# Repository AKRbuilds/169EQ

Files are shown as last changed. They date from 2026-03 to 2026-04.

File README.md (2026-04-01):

# Studer 169 EQ (API 500 Format)

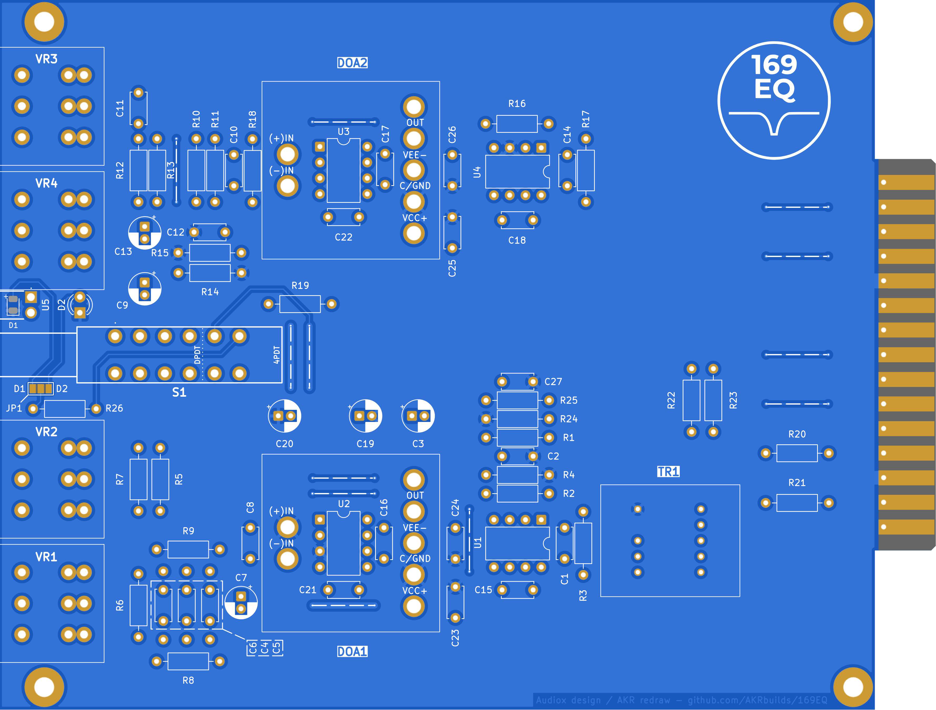
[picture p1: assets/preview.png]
PCB Preview


This project is a reproduction of the **Studer 169 EQ** for the **API 500 series** format. Based on the original design by *AUDIOX* on GroupDIY.

---

## ❤️ Support the Development
Redrawing this board took quite some time. If this project helps your studio or saves you time, **consider buying me a coffee!** Your support keeps me runing.



---

## One-Click Manufacturing
Get your PCBs made with the exact specifications by using the official PCBWAY shared project link:



> You can also  [Download the Latest Gerber Files (ZIP)](https://github.com/AKRbuilds/169EQ/releases/latest) to use with any manufacturer.

---

## Improvements in this Version
* **Redrawn Layout:** 2-layer board with top-side jumpers.
* **4PDT Switch Support:** New footprint for 4PDT switches + Bypass LED (fully compatible with original SPDT).
* **LED Options:** Choose between **SMD + Light Pipe (U5)** or standard **THT LED** via jumper **JP1**.
  
---

## 📄 Documentation
* 📄 Launch interactive BOM [**WITH** Neutrik transformer](https://htmlpreview.github.io/?https://github.com/AKRbuilds/169EQ/blob/main/assets/ibom_with_neutrik.html) / [**WITHOUT** 🔴 Neutrik transformer](https://htmlpreview.github.io/?https://github.com/AKRbuilds/169EQ/blob/main/assets/ibom_without_neutrik.html)
* 📄 PCB Assembly Overview (PDF) [**WITH** Neutrik transformer](assets/Layout_with_neutrik.pdf) / [**WITHOUT** 🔴 Neutrik transformer](assets/Layout_without_neutrik.pdf)
* 📄 [Bom (CSV)](assets/bom.csv) / [Bom (PDF)](assets/bom.pdf)
* 📄 [KiCad Schematics (PDF)](assets/Schematics.pdf)
* 📄 [Original Schematics (PDF)](assets/original_schematics.pdf)
* 📄 [Front Panel Guide (PDF)](assets/front_panel.pdf) | 📥 [Download FPD File](assets/front_panel.fpd)
* 📄 [Supporting Hardware (PDF)](assets/hardware.pdf)
* 🔗 Front panels available here: [Frontpanels.de](https://groupdiy.com/threads/studer-169-eq-in-api-500-format.36522/)
---

## 🔗 Credits & Community
* **Original Project:** Original design by **AUDIOX**.
* **Join the Discussion:** [Build Thread on GroupDIY](https://shop.frontpanels.de/FIlter/Equalizer)

## License
Licensed under **CERN-OHL-S v2**.

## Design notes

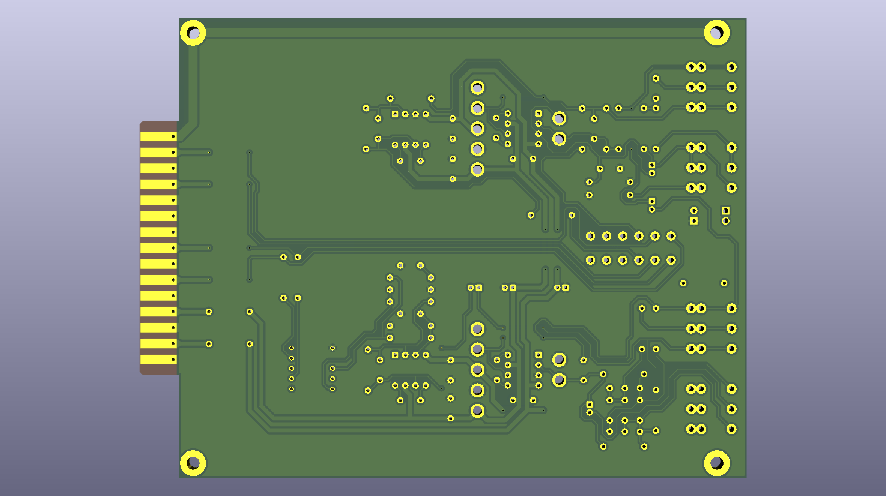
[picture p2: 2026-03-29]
assets/preview_back.png

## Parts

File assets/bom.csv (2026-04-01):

Designator | Footprint | Quantity | Value with Neutrik | Value without Neutrik | Man. Pr. Nr.
Capacitors
C1 | C_Disc_D5.0mm_W2.5mm_P5.00mm | 1 | Do not place | 47p
C10, C14, C2, C8 | C_Disc_D5.0mm_W2.5mm_P5.00mm | 4 | 47p | 47p
C11 | CAP FILM P5.00mm | 1 | 15n | 15n
C12, C4, C5 | CAP FILM P5.00mm | 3 | 10n | 10n
C13, C3, C7, C9 | CP_Radial_D5.0mm_P2.00mm | 4 | 100uf/10V | 100uf/10V
C15, C16, C17, C18 | C_Disc_D5.0mm_W2.5mm_P5.00mm | 4 | 22p | 22p
C19, C20 | CP_Radial_D5.0mm_P2.00mm | 2 | 10uf/25V | 10uf/25V
C21, C22, C23, C24, C25, C26 | C_Disc_D5.0mm_W2.5mm_P5.00mm | 6 | 100n | 100n
C27 | C_Disc_D5.0mm_W2.5mm_P5.00mm | 1 | 150p | Do not place
C6 | CAP FILM P5.00mm | 1 | 220n | 220n
Transformer
TR1 | NTL1 | 1 | NTL1 | Do not place and Bridge JP2 and JP3
ICs
DOA1 | DOA_2520 - Don't place U2 if used | 1 | DOA1 | DOA1
DOA2 | DOA_2520 - Don't place U3 if used | 1 | DOA2 | DOA2
U1, U4 | DIP-8_W7.62mm | 4 | NE5534 | NE5534
U2, U3 | Place if DOA not used | 4 | NE5534 | NE5534
Resistors
R1 | R_Axial_DIN0207_L6.3mm_D2.5mm_P10.16mm_Horizontal | 1 | Do not place | 20K
R2 | R_Axial_DIN0207_L6.3mm_D2.5mm_P10.16mm_Horizontal | 1 | WIRE | 20K
R3 | R_Axial_DIN0207_L6.3mm_D2.5mm_P10.16mm_Horizontal | 1 | 1K | 10K
R10, R11, R16, R17 | R_Axial_DIN0207_L6.3mm_D2.5mm_P10.16mm_Horizontal | 4 | 10K | 10K
R4 | R_Axial_DIN0207_L6.3mm_D2.5mm_P10.16mm_Horizontal | 1 | 5K6 | 10K
R12, R14 | R_Axial_DIN0207_L6.3mm_D2.5mm_P10.16mm_Horizontal | 2 | 1K8 | 1K8
R13, R15 | R_Axial_DIN0207_L6.3mm_D2.5mm_P10.16mm_Horizontal | 2 | 680K | 680K
R18, R19 | R_Axial_DIN0207_L6.3mm_D2.5mm_P10.16mm_Horizontal | 2 | 22R | 22R
R20, R21 | R_Axial_DIN0207_L6.3mm_D2.5mm_P10.16mm_Horizontal | 2 | 10R | 10R
R22, R23 | R_Axial_DIN0207_L6.3mm_D2.5mm_P10.16mm_Horizontal | 2 | 1K6 | 10R
R24 | R_Axial_DIN0207_L6.3mm_D2.5mm_P10.16mm_Horizontal | 1 | WIRE | Do not place
R25 | R_Axial_DIN0207_L6.3mm_D2.5mm_P10.16mm_Horizontal | 1 | 15K | Do not place
R26, R6, R7 | R_Axial_DIN0207_L6.3mm_D2.5mm_P10.16mm_Horizontal | 3 | 3K3 | 3K3
R5 | R_Axial_DIN0207_L6.3mm_D2.5mm_P10.16mm_Horizontal | 1 | 560R | 560R
R8, R9 | R_Axial_DIN0207_L6.3mm_D2.5mm_P10.16mm_Horizontal | 2 | 220K | 220K
Others
S1 | 4PDT F4UEE to use LED / DPDT F2UEE no LED | 1 | 4PDT/DPDT | 4PDT/DPDT | MPBS-42H01L-F14
D1 | 805 Choose between D1 and D2 and jump JP1 accordingly | 1 | LED | LED | 150080AS75000 works great even without light pipe
D2 | LED_D3.0mm | 1 | LED | LED
U5 | SLP3250100F - Led pipe | 1 | LED Pipe | LED Pipe | SLP3-250-100-F
VR1 | PC2G16BU | 1 | 2x22KLin | 2x22KLin | OM-01-023 | available at audiomaintenance.com
VR2, VR3 | PC2G16BU 16mm dual gang pots | 2 | 2x10KLin | 2x10KLin | OM-01-005
VR4 | PC2G16BU 16mm dual gang pots | 1 | 2x100KRLog | 2x100KRLog | OM-01-059
DOA Pin Receptacles | Mill-Max 0322 | 12 |  |  | 0322-0-15-01-34-27-10-0 For gold ones: 0322-0-15-15-34-27-10-0

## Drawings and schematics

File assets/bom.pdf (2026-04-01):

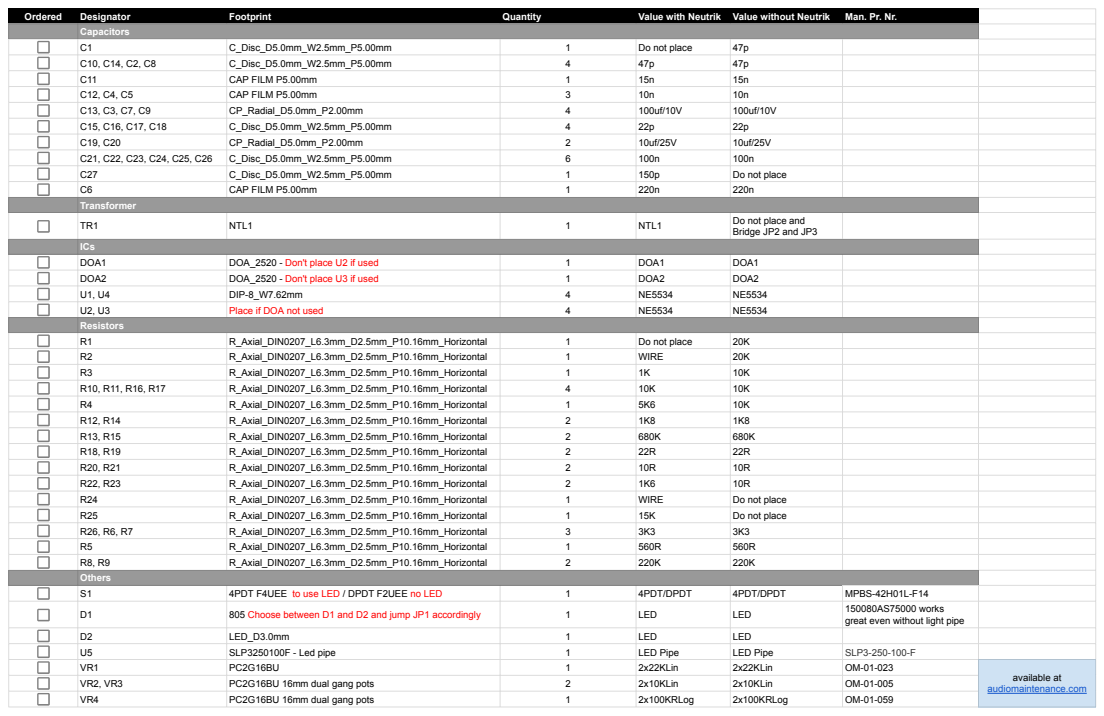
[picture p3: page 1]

Don't place U2 if used
Don't place U3 if used

Place if DOA not used

Others

150080AS75000 works
great even without light pipe

D1 805 Choose between D1 and D2 and jump JP1 accordingly 1 LED LED D2 LED_D3.0mm 1 LED LED VR1 PC2G16BU 1 2x22KLin 2x22KLin VR4 PC2G16BU 16mm dual gang pots 1 2x100KRLog 2x100KRLog

SLP3-250-100-F

OM-01-023 OM-01-059 | audiomaintenance.com

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
Mill-

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
s: 0322-0-15-15-
3

4

2

7

1

0

0

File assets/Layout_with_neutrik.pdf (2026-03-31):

R14 | C22 | R²² C⁴ C12 D² | C9 | R¹³ | C⁵ C¹¹ 1 | 2 | 3 | 4 | 5 | 6 1 | 2 | 3 | 4 | 5 | 6 ABCD | ABCD Date: 2026-03-13 KiCad | E.D.A. 9.0.7 Size: A4 | Rev: 1

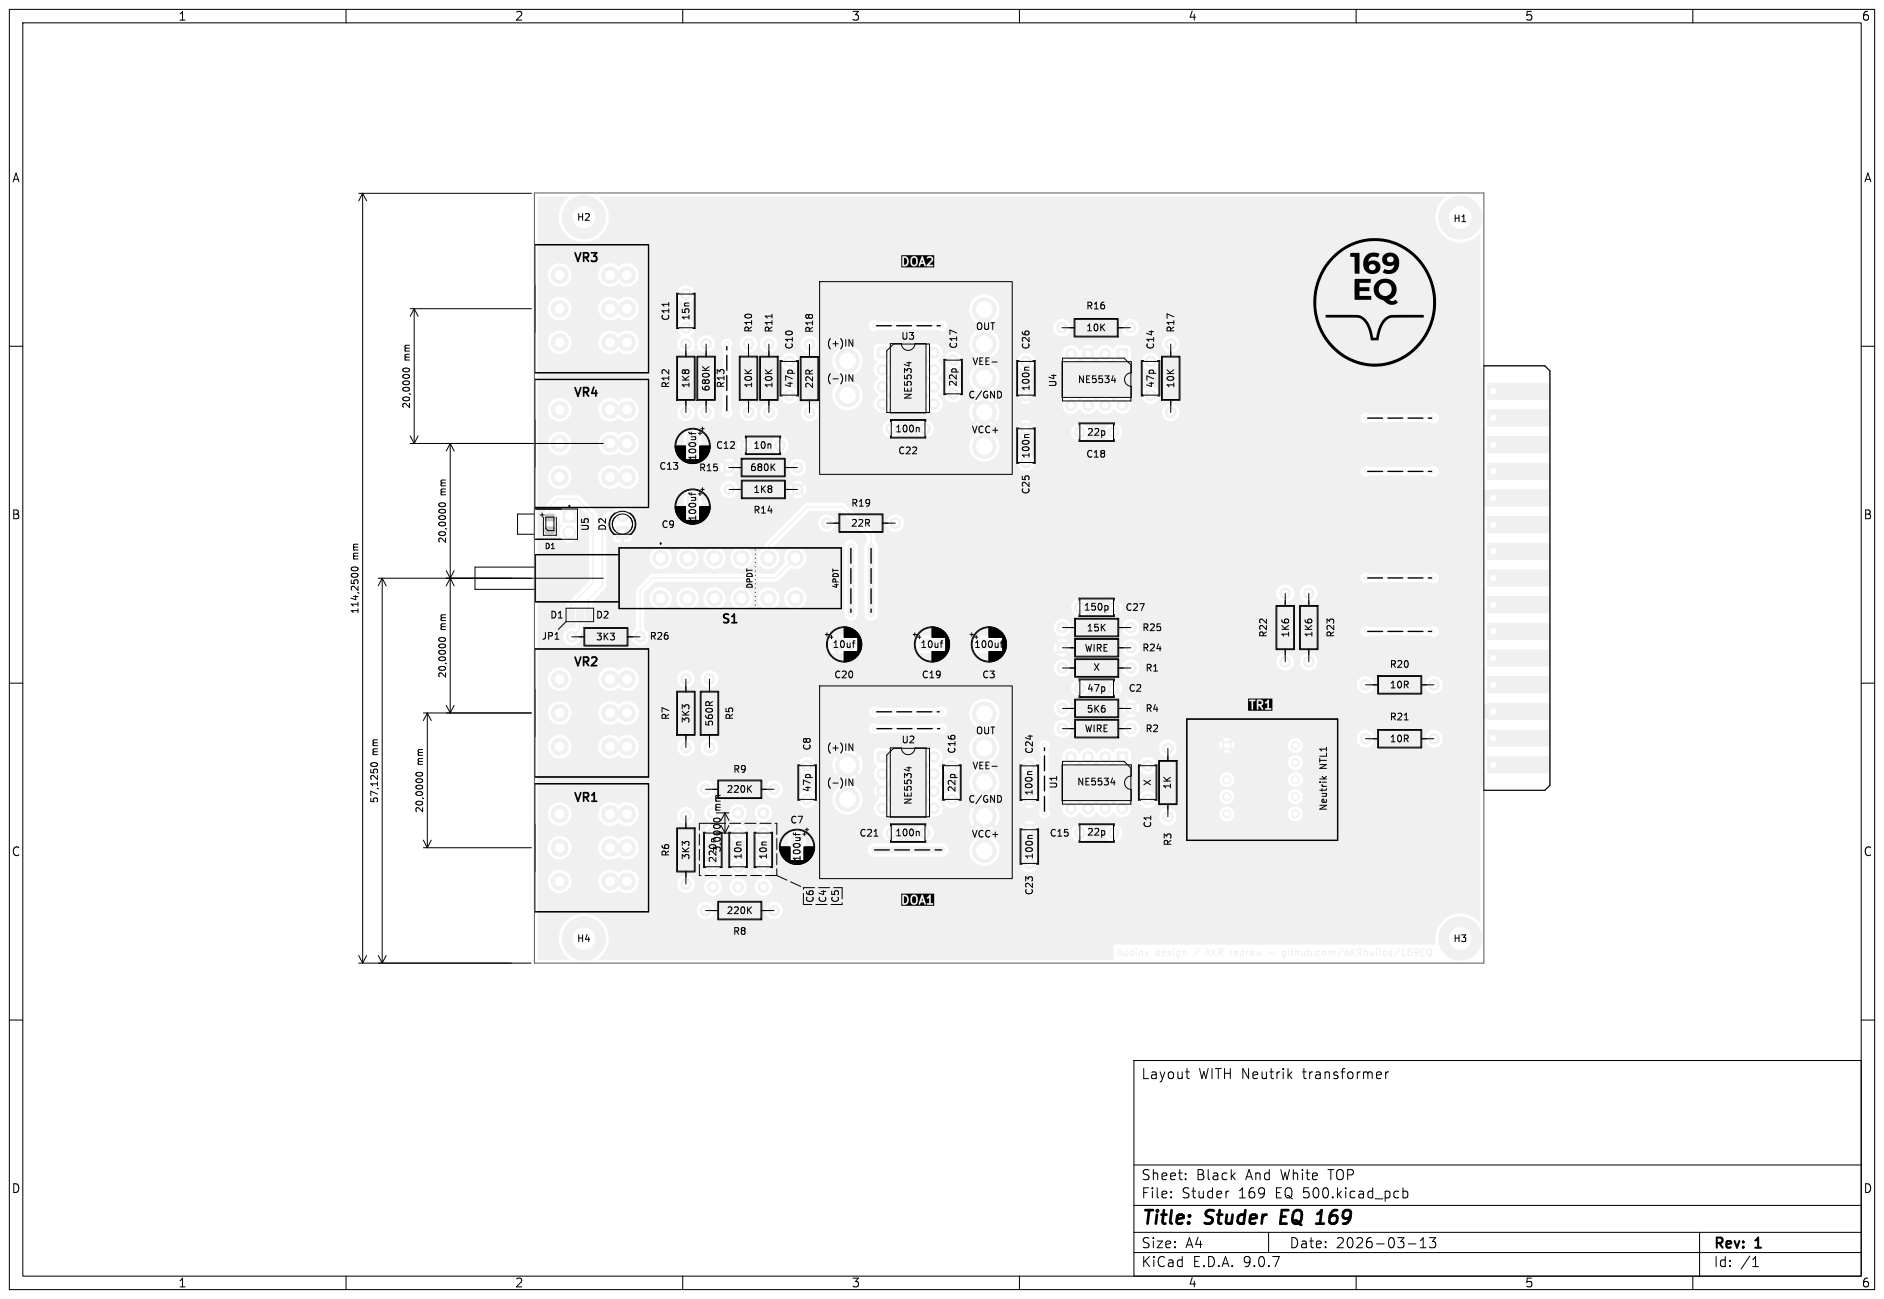
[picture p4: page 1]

Id: /1 Title: Studer EQ 169

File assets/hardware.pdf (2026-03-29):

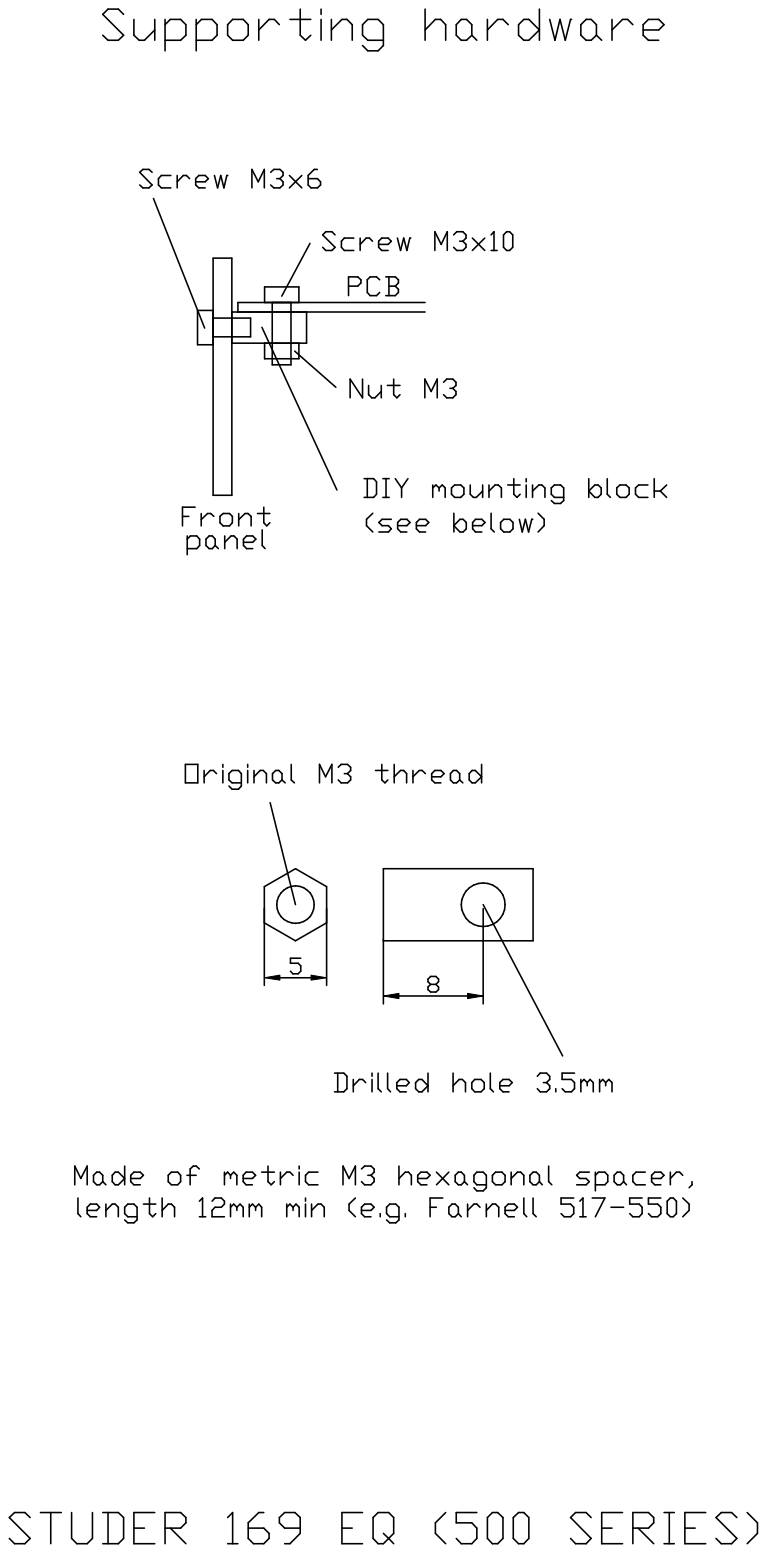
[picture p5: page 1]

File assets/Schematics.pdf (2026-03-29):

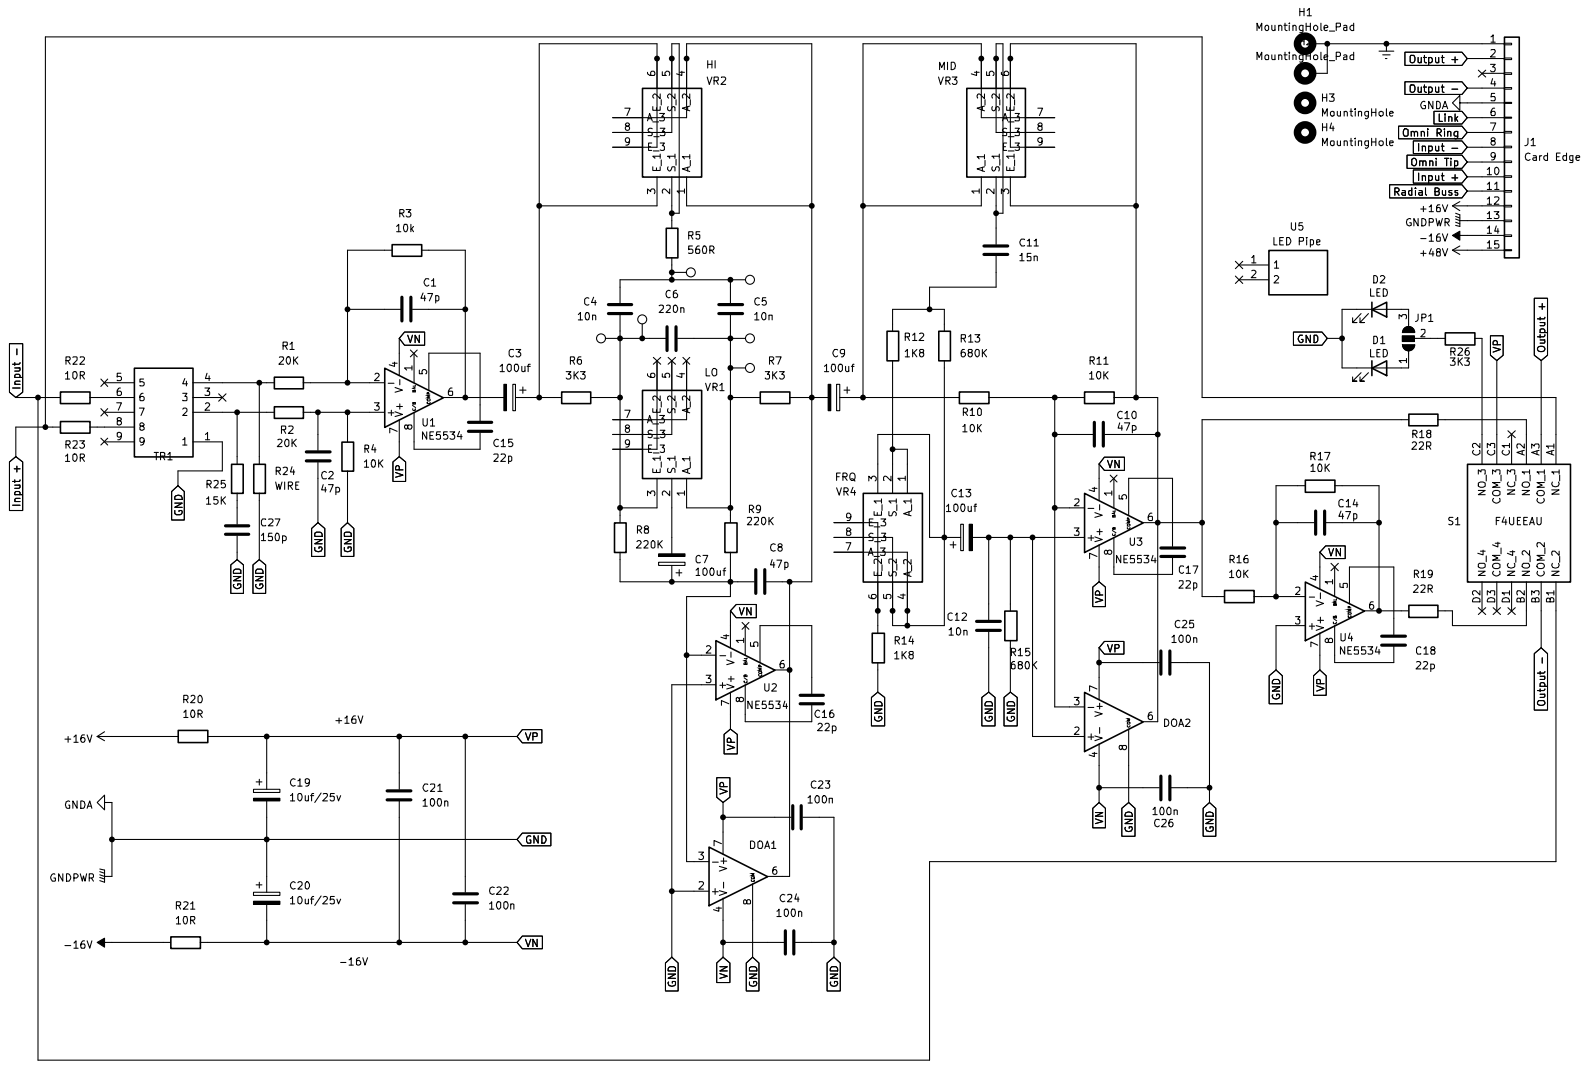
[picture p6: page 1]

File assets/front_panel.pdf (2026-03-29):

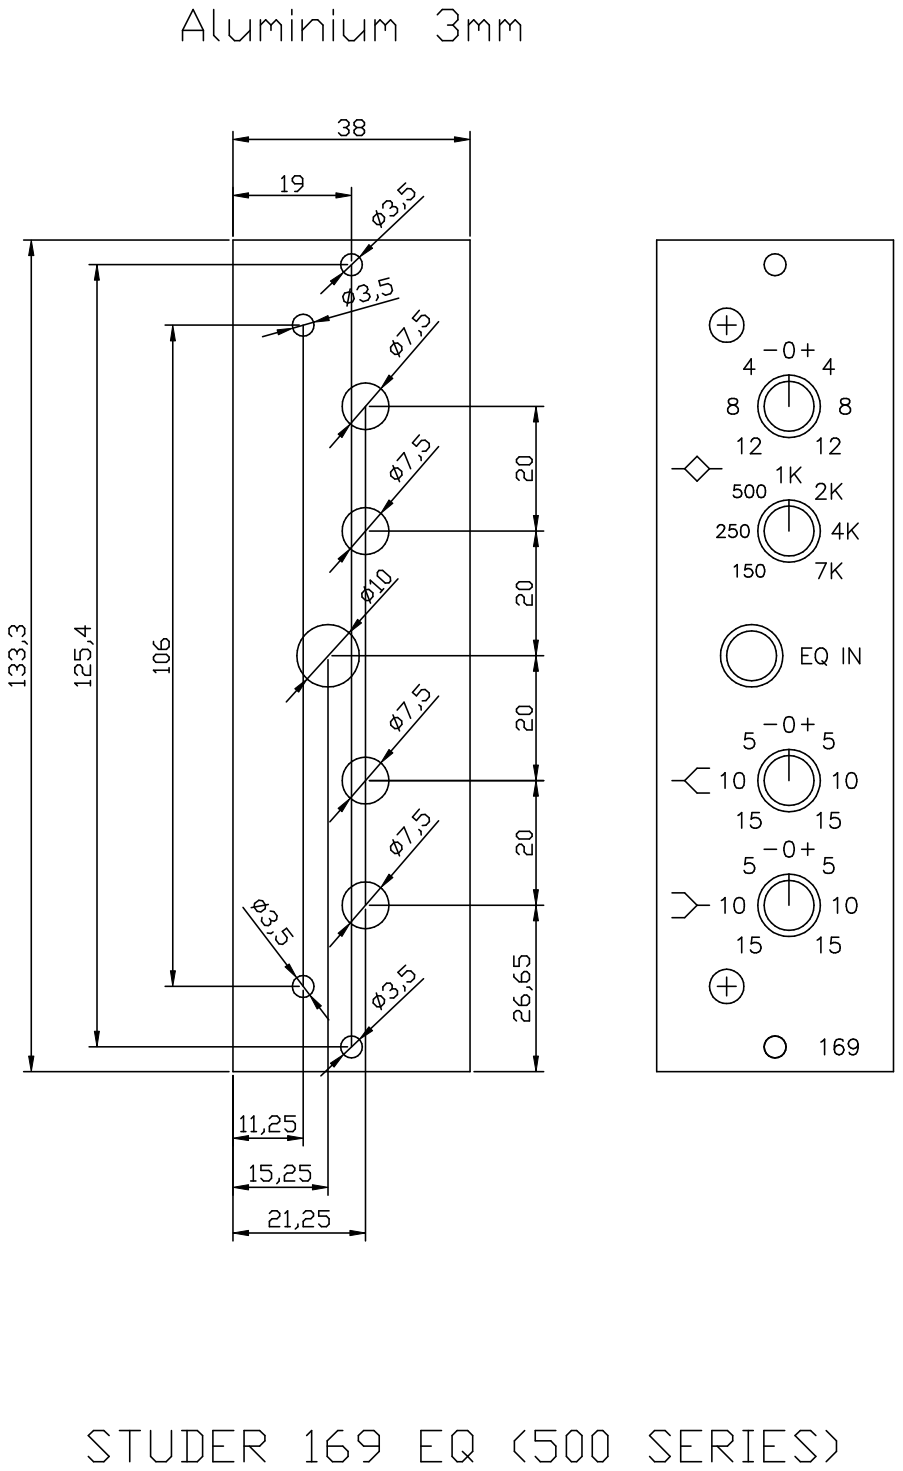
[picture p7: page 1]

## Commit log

2026-03-29 Rename Studer 169 EQ.pdf to Schematics.pdf
2026-03-31 Rename bom - bom.csv to bom.csv
    [bom.csv]
2026-04-01 Revise front panel and discussion links in README
    Updated links for front panels and discussion thread.
2026-04-01 Update BOM with new component details
    [bom.csv]
2026-04-01 Add BOM CSV link to README documentation
    Added BOM CSV file link to documentation.
2026-04-01 Update BOM documentation to include PDF format
2026-04-01 Fix formatting for BOM links in README.md
